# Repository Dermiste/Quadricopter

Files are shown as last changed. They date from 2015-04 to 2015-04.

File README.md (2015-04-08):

Quadricopter
============

## Cartes
Contient les schémas et empruntes de la carte mère (celle qui se trouve directement au dessus du Coldfire) ainsi que des 4 cartes mezzanines:
- le gyroscope                LG4200D
- l'accéléromètre             LIS331DLH
- l'accéléromètre + boussole  LMS303D
- le capteur de pression      LPS25h

## Controleur
Les sources du projet phonegap permettant de réaliser une télécommande sur smartphone/tablette

## Datasheet
Les datasheet de tous les capteurs utilisés + certains .pdf qui se sont avérés utiles

## Scilab Scripts
Tout le nécessaire pour pouvoir recevoir des données depuis la liaison série et ensuite les afficher dans un graph
À noter que l'installation d'une extension est nécessaire pour pouvoir faire fonctionner le script, disponible ici:
https://atoms.scilab.org/toolboxes/serialport

## Sources
Le code C utilisé dans le quadcopter.
Pour travailler sur un nouveau fichier basé sur l'existant, copier et renommer Sandbox.c qui contient le minimum vital (lecture capteur + filtrage) puis ajouter dans le makefile le nom du fichier dans la variable PGMs de la manière indiquée dans le commentaire juste au dessus. Noter que le makefile utilise un memory.x pour répartir certaines librairies entre la ROM et la RAM, d'ou les deux .s19 en sortie. Le "rom" est à uploader avec la sonde et ne change normalement pas (un seul upload donc, mais véto sur le "ne change pas") et le "ram" est à uploader avec dBug via un terminal.

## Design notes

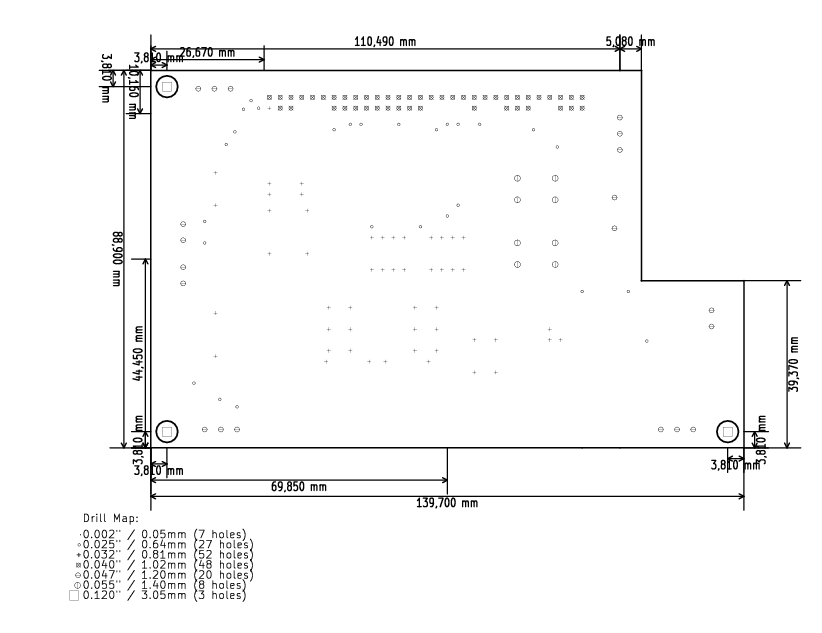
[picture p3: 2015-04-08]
Cartes/Mezanine/Image jpg pour rapport/plan de perçage.bmp

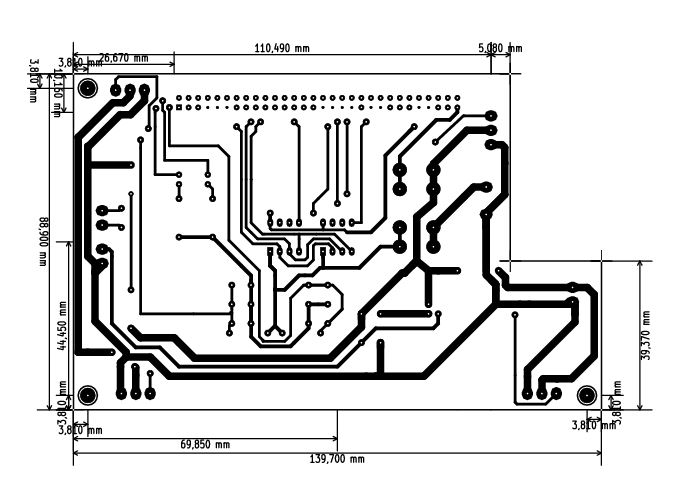
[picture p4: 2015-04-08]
Cartes/Mezanine/Image jpg pour rapport/typon dessous.bmp

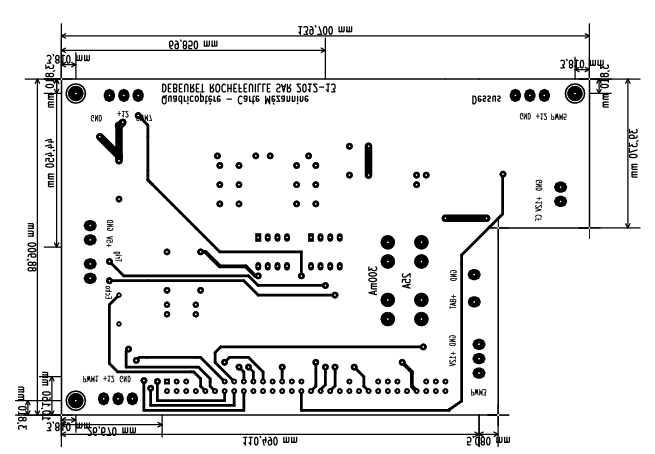
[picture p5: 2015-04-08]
Cartes/Mezanine/Image jpg pour rapport/typon dessus.bmp

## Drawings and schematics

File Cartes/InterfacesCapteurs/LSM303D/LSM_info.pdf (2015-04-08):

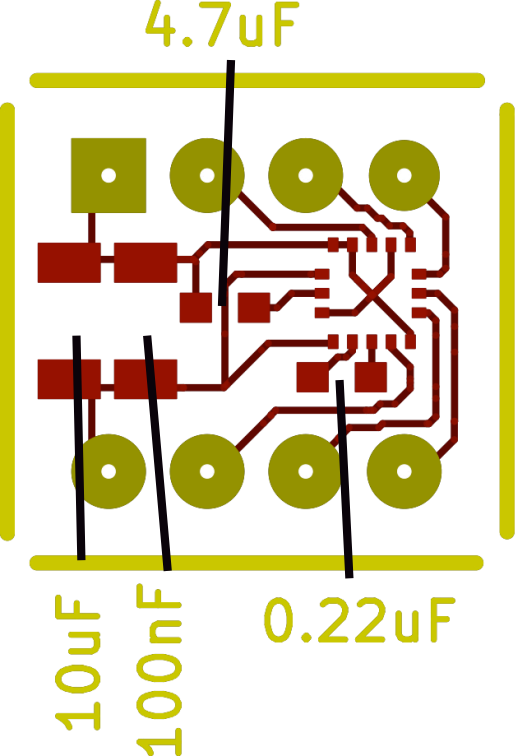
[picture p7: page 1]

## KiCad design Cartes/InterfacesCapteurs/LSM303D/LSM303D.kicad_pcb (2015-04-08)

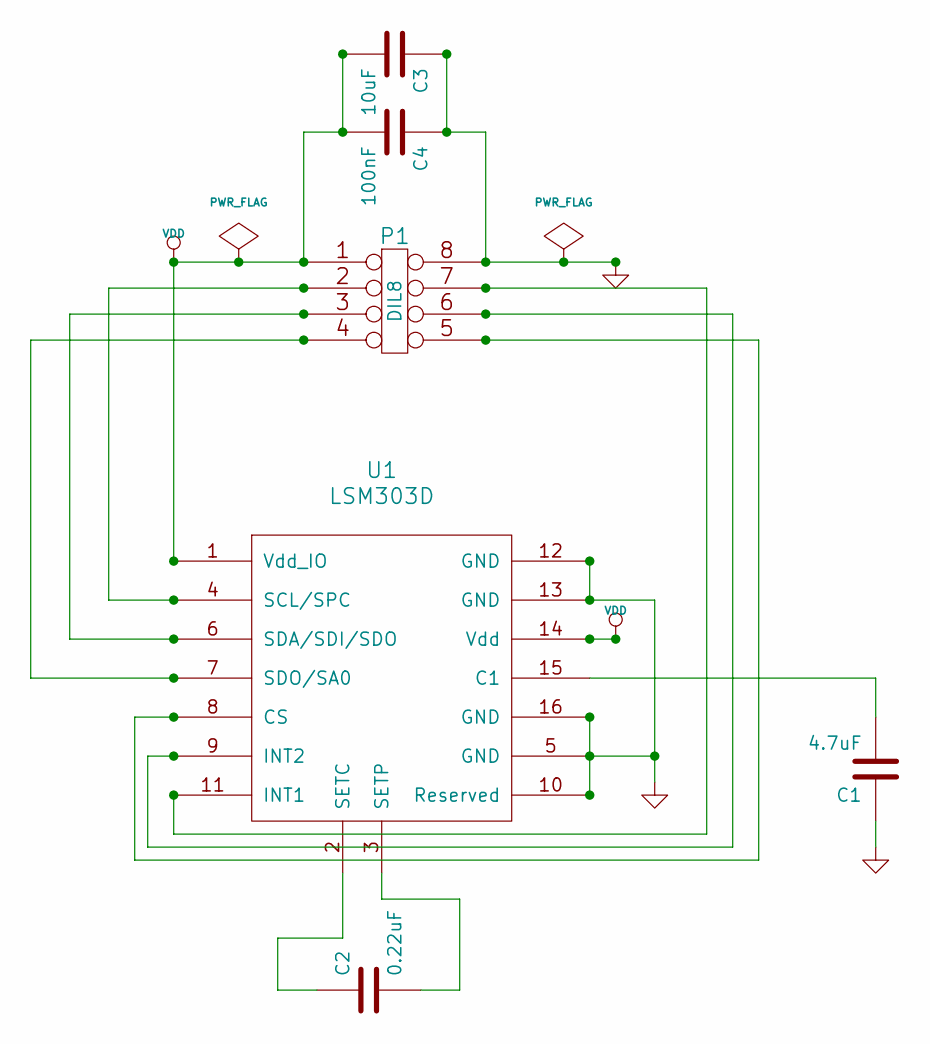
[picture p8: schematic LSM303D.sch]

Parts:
C1: 4.7uF
C2: 0.22uF
C3: 10uF
C4: 100nF
P1: DIL8
U1: LSM303D

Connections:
GND: C1.1, C3.1, C4.1, P1.8, U1.5 (GND), U1.10 (Reserved), U1.12 (GND), U1.13 (GND), U1.16 (GND)
unnamed: C1.2, U1.15 (C1)
unnamed: C2.1, U1.2 (SETC)
unnamed: C2.2, U1.3 (SETP)
unnamed: P1.2, U1.4 (SCL/SPC)
unnamed: P1.3, U1.6 (SDA/SDI/SDO)
unnamed: P1.4, U1.7 (SDO/SA0)
unnamed: P1.5, U1.8 (CS)
unnamed: P1.6, U1.9 (INT2)
unnamed: P1.7, U1.11 (INT1)
VDD: C3.2, C4.2, P1.1, U1.1 (Vdd_IO), U1.14 (Vdd)

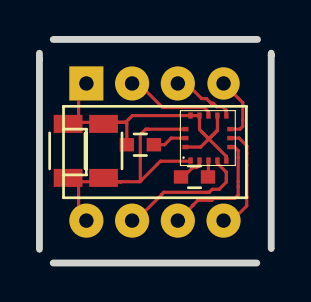
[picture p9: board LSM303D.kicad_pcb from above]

Board: 2 copper layers, 12.9 x 12.4 mm, 6 parts (0 on the bottom side), 11 nets.

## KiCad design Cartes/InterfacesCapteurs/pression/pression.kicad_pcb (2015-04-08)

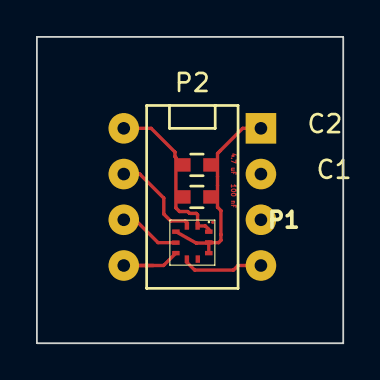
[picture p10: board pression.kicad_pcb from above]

Board: 2 copper layers, 17.0 x 17.0 mm, 4 parts (0 on the bottom side), 6 nets.

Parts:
C1: 4.7 uF; C_0603
C2: 100 uF; C_0603
P1: DIL10; HCLGA-10L
P2: DIL8; DIP-8__300

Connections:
/CLK: P1.2, P2.2
/CS: P1.6, P2.5
/SDI: P1.4, P2.3
/SDO: P1.5, P2.4
/Vcc: C1.1, C2.1, P1.1, P1.10, P2.1
GND: C1.2, C2.2, P1.3, P1.8, P1.9, P2.8

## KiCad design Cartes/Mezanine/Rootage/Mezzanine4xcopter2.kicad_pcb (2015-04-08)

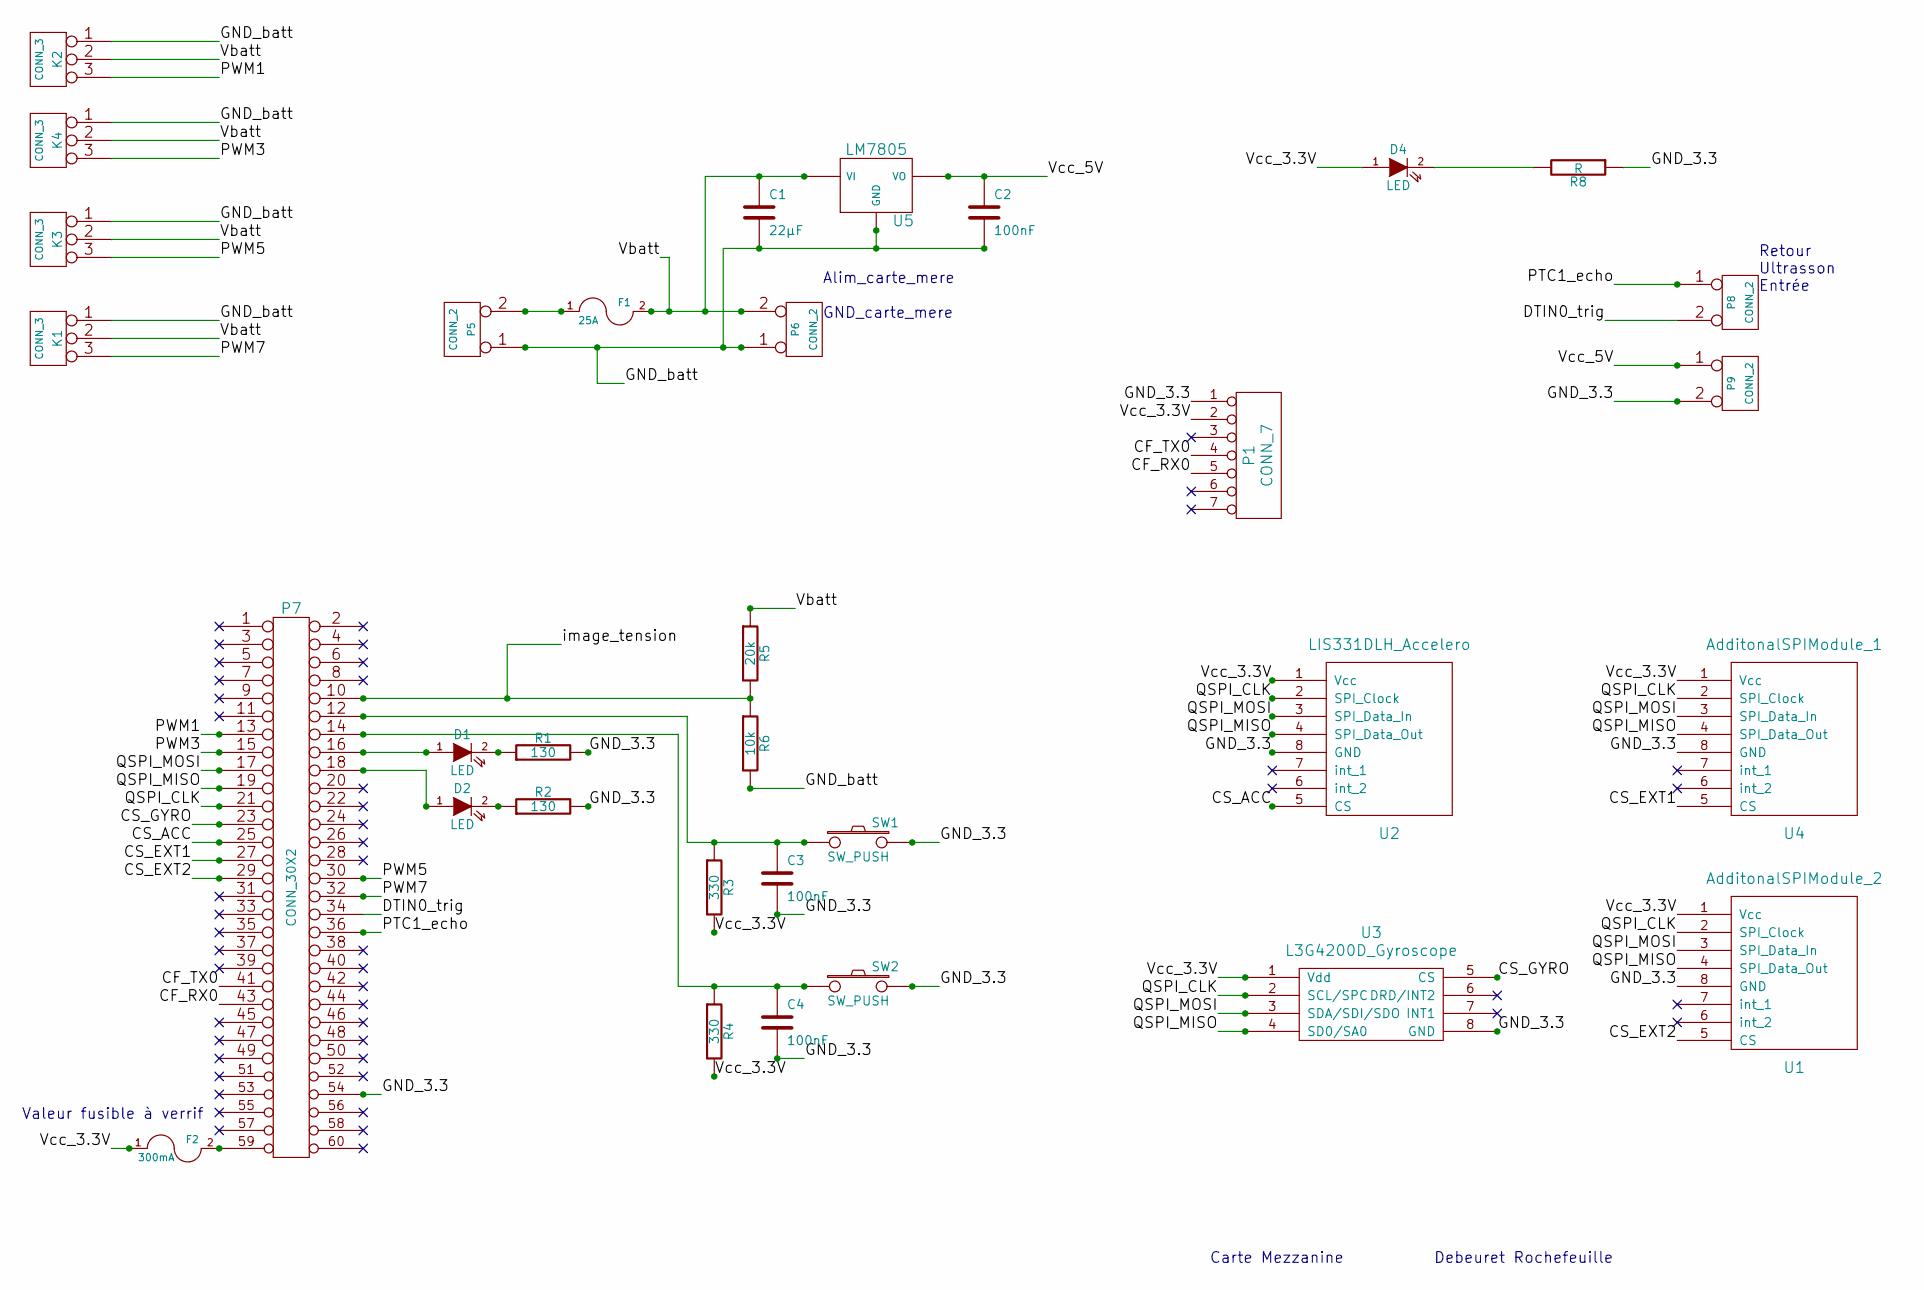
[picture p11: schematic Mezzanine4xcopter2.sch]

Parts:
C1: 22µF
C2, C3, C4: 100nF
D1, D2, D4: LED
F1: 25A
F2: 300mA
K1, K2, K3, K4: CONN_3
P1: CONN_7
P5, P6, P8, P9: CONN_2
P7: CONN_30X2
R1, R2: 130
R3, R4: 330
R5: 20k
R6: 10k
R8: R
SW1, SW2: SW_PUSH
U1: AdditonalSPIModule_2
U2: LIS331DLH_Accelero
U3: L3G4200D_Gyroscope
U4: AdditonalSPIModule_1
U5: LM7805

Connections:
/CF_RX0: P1.5, P7.43
/CF_TX0: P1.4, P7.41
/CS_ACC: P7.25, U2.5 (CS)
/CS_EXT1: P7.27, U4.5 (CS)
/CS_EXT2: P7.29, U1.5 (CS)
/CS_GYRO: P7.23, U3.5 (CS)
/DTIN0_trig: P7.34, P8.2 (PM)
/GND_3.3: C3.2, C4.2, P1.1, P7.54, P9.2 (PM), R1.2, R2.2, R8.1, SW1.2, SW2.2, U1.8 (GND), U2.8 (GND), U3.8 (GND), U4.8 (GND)
/GND_batt: C1.2, C2.2, K1.1, K2.1, K3.1, K4.1, P5.1, P6.1, R6.2, U5.GND
/PTC1_echo: P7.36, P8.1
/PWM1: K2.3, P7.13
/PWM3: K4.3, P7.15
/PWM5: K3.3, P7.30
/PWM7: K1.3, P7.32
/QSPI_CLK: P7.21, U1.2 (SPI_Clock), U2.2 (SPI_Clock), U3.2 (SCL/SPC), U4.2 (SPI_Clock)
/QSPI_MISO: P7.19, U1.4 (SPI_Data_Out), U2.4 (SPI_Data_Out), U3.4 (SD0/SA0), U4.4 (SPI_Data_Out)
/QSPI_MOSI: P7.17, U1.3 (SPI_Data_In), U2.3 (SPI_Data_In), U3.3 (SDA/SDI/SDO), U4.3 (SPI_Data_In)
/Vbatt: C1.1, F1.2, K1.2 (PM), K2.2 (PM), K3.2 (PM), K4.2 (PM), P6.2 (PM), R5.1, U5.VI
/Vcc_3.3V: D4.1 (A), F2.1, P1.2, R3.2, R4.2, U1.1 (Vcc), U2.1 (Vcc), U3.1 (Vdd), U4.1 (Vcc)
/Vcc_5V: C2.1, P9.1, U5.VO
/image_tension: P7.10, R5.2, R6.1
unnamed: C3.1, P7.12, R3.1, SW1.1
unnamed: C4.1, P7.14, R4.1, SW2.1
unnamed: D1.1 (A), P7.16
unnamed: D1.2 (K), R1.1
unnamed: D2.1 (A), P7.18
unnamed: D2.2 (K), R2.1
unnamed: D4.2 (K), R8.2
unnamed: F1.1, P5.2 (PM)
unnamed: F2.2, P7.59

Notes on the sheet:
Valeur fusible à verrif
Carte Mezzanine Debeuret Rochefeuille
Alim_carte_mere GND_carte_mere
Retour Ultrasson Entrée

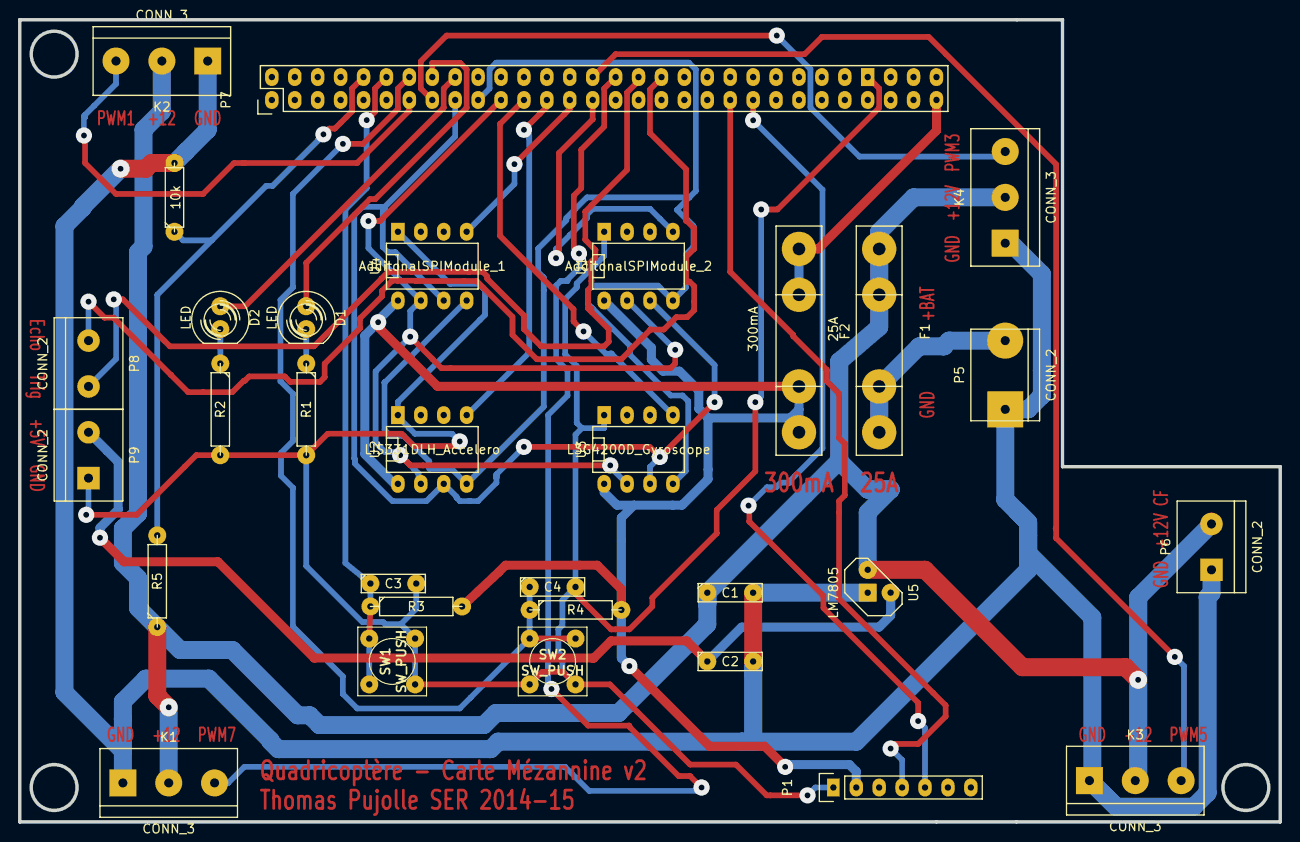
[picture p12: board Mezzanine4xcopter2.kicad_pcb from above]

Board: 2 copper layers, 139.7 x 88.9 mm, 31 parts (0 on the bottom side), 29 nets.

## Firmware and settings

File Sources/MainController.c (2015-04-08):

/* Projet : Quadricopter
fichier : 4xCopter.c
Objet : prog principal d'asservissement
autheurs : VG / J-E G-B
Version :	1.0 - 27-06-2013 Tests de base
			1.1 - 11-07-2013 Mise en route des moteurs !
*/

#include "stdio.h"
#include "main.h"
#include "config.h"
#include "libs/spiUtils/spiUtils.h"
#include "libs/mcf5213/mcf5213.h"
#include "libs/sensorUtils/sensorUtils.h"


#define NVECT_TMR0 (64 + 19)
#define NVECT_TMR1 (64 + 20)
#define NVECT_TMR2 (64 + 21)

#define ADR_VECT_INT0 (0x20000000 + NVECT_TMR0*4)
#define ADR_VECT_INT1 (0x20000000 + NVECT_TMR1*4)
#define ADR_VECT_INT2 (0x20000000 + NVECT_TMR2*4)

extern void isrINT0(void);
extern void isrSonar(void);
extern void isrTempo1ms(void);

void Init_5213(void);
void Init_PWM (void);
void receiveAndSendCommands();

int imageCap1 = 0, imageCap2 = 0, imagetemps;

char gyrData[3];
char accData[3];
char magData[3];
char buf[6];


int __errno=0;	//pour gestion messages d'erreur des fcts asin, acos de libm.a
int nirq = 0;
signed int moteur1,moteur2,moteur3,moteur4;

unsigned int initialThurst = 0;
int thrustOffset = 0;
int totalSample = 0;
unsigned int testMode = 0,shouldFinishTest = 0;

int altitudeSonar = 0, altitudeBaro = 0, pressure = 0;
int pitch = 0,roll = 0, yaw = 0;

int targetPitch = 0, targetRoll = 0, targetYawSpeed = 0;

int lastPitch = 0, lastRoll = 0, deltaPitch = 0, deltaRoll = 0;

int errorPitch = 0, errorRoll = 0, errorYawSpeed = 0;
int integratedErrorPitch = 0, integratedErrorRoll = 0, integratedErrorYawSpeed=0;

int control_roll=0,control_pitch=0,control_yaw=0;
int PTerm, ITerm, DTerm;
unsigned char m4offset = 3;
//int a=2,b=3,c=4;

char stepPID = 1;

char controlMode = 0,controlActivated = 0;
int a = 2, b = 3, c = 9;

signed int rollFromGyro=0, pitchFromGyro=0;
signed int pitchFromAcc=0, rollFromAcc=0;

unsigned char kP = 42, kI = 70, kD = 13;

int yawFromGyro = 0, intFromAcc = 0;

void actionINT0(void) {
	//MCF_DTIM0_DTER = MCF_DTIM_DTER_REF | MCF_DTIM_DTER_CAP;
}

void actionSonar(void) {
	if (imageCap1 == 0){
		imageCap1 = MCF_DTIM1_DTCR;
	} else {
		imageCap2 = MCF_DTIM1_DTCR;
		imagetemps=imageCap2-imageCap1;  //image impulsion = capture 2 -capture 1

		altitudeSonar=(imagetemps*100)/7000;

        imageCap1 = 0;	
       
	}

	MCF_DTIM1_DTER = MCF_DTIM_DTER_REF | MCF_DTIM_DTER_CAP;
}

void actionTempo1ms(void) {
	nirq++;
	switch(nirq){

		case 5000:		
			MCF_DTIM2_DTMR=0x500B;
			nirq = 0;
			shouldFinishTest = 1;
		break;
	}

	// Acquittement de l'interruption
	MCF_DTIM2_DTER = MCF_DTIM_DTER_REF | MCF_DTIM_DTER_CAP;
}


int main (void)
{	
	a = cos(b);
	c = sin(b);
	a = tan(b);
	c = atan(a);
	c = atan2(a,b);
	c = pow(a,b);


	controlMode = 0;
	controlActivated = 0;
	testMode = 0;


	printf("Starting ...:\n");
	char temp, choix,_r,_p;
	unsigned int i, throttle,st;
	throttle = 0,st = 0;
	printf("Reponse indicielle:\n");
	
	Init_5213();		
	Init_PWM();  
	Init_spi();
	int result = Init_sensors();
	while(!result && i){	//Init des composants
		printf("Erreur d'init Acc ou Gyro, retrying ...\n");
		result = Init_sensors();
	}



	getch();

	while(1)
	{
		while ((MCF_DTIM3_DTER & 2)==0);//attend prochain date ech
		MCF_DTIM3_DTER = 2;				//RAZ Flag


		MCF_GPIO_CLRTC=0x00;
		for(i=0;i<2000;i++); //Temporisation
		MCF_GPIO_SETTC=0x01;

		getIMUdata(accData, gyrData, magData);
		filterIMUdata(accData, gyrData, magData, &pitch, &roll, &yaw);

		errorPitch = targetPitch - pitch/10;
		errorRoll = targetRoll - roll/10;	

		//errorYawSpeed = targetYawSpeed - gyrData[2] * 3.906;

		integratedErrorPitch +=  errorPitch; 
		integratedErrorRoll  += errorRoll;
		//integratedErrorYawSpeed += errorYawSpeed;

		integratedErrorPitch = sat(integratedErrorPitch,-7000,7000);  
		integratedErrorRoll =  sat(integratedErrorRoll,-8000,8000);

		deltaRoll = roll - lastRoll;
		lastRoll = roll;	

		deltaPitch = pitch - lastPitch;
		lastPitch = pitch;

		PTerm = errorPitch / kP;
		//PTerm = sat(PTerm,-10,10); 

		ITerm = (integratedErrorPitch / freq) / kI;
		DTerm = deltaPitch / kD;

		control_pitch = PTerm;// + ITerm - DTerm;
		control_pitch += ITerm;
		control_pitch -= DTerm;

		control_roll = errorRoll / kP ;
		control_roll = (integratedErrorRoll / freq ) /  kI;
		control_roll -= deltaRoll / kD;

		//control_yaw = integratedErrorYawSpeed / freq / kI;	
		control_yaw = 0;		

		if (controlActivated){
			if (controlMode){
				//moteur1 =  throttle + st + control_roll;
				//moteur2 =  throttle + st - control_roll;

				moteur3 =  throttle + st + control_pitch;
				moteur4 =  throttle + st - control_pitch + m4offset;

				//MCF_PWM_PWMDTY7 = (unsigned char)sat(moteur1+110,100,210);	
				//MCF_PWM_PWMDTY3 = (unsigned char)sat(moteur2+110,100,210);

				MCF_PWM_PWMDTY5 = (unsigned char)sat(moteur3+110,100,190);
				MCF_PWM_PWMDTY1 = (unsigned char)sat(moteur4+110,100,190);	//on limite a 180 pour commencer...
				//
				throttle = 50;
				//printf("Pitch [%d, %d, %d, %d] \n",pitch/10,control_pitch,integratedErrorPitch,deltaPitch);
				//printf("Roll  [%d, %d, %d] \n",roll/10,errorRoll/10,inategratedErrorRoll/10);
				//printf("Yaw [%d] \n",errorYawSpeed);
				
			} else {
				//initialThurst = 120;
				MCF_PWM_PWMDTY7 = 0;
				MCF_PWM_PWMDTY3 = 0;

				MCF_PWM_PWMDTY5 = initialThurst;// - m4offset;
				MCF_PWM_PWMDTY1 = initialThurst + m4offset;
				throttle = 0;
			}
		} else {
			MCF_PWM_PWMDTY1 = 0;
			MCF_PWM_PWMDTY3 = 0;
			MCF_PWM_PWMDTY5 = 0;
			MCF_PWM_PWMDTY7 = 0;
		}
		 //PTC1=1;


		//MCF_DTIM0_DTER=0x03;
		//printf("Pulse ...\n");

		/*while((MCF_DTIM1_DTER & 0x01 )==0); // Capture 2
		MCF_DTIM1_DTER=0x03; //RAZ registre Drapeau
		imageCap2=MCF_DTIM1_DTCR; //capture 2

		printf("Capture 1 ...\n");

		while((MCF_DTIM1_DTER & 0x01 )==0); // Capture 2
		MCF_DTIM1_DTER=0x03; //RAZ registre Drapeau
		imageCap2=MCF_DTIM1_DTCR; //capture 2		

		printf("Capture 2 ...\n");*/


		 //PTC1=0;		
		//MCF_DTIM0_DTCN=0; //RAZ registre Compteur
		//MCF_DTIM0_DTER=0x03; //RAZ registre Drapeau







		if (testMode){
			if (shouldFinishTest){
				testMode = 0;
				shouldFinishTest = 0;				
				out_byte(1);	
			} else { 
				out_byte(0);
			}	


			/*out_byte(accData[2]);
			out_byte(gyrData[0]);
			out_byte(gyrData[1]);
			out_byte(gyrData[2]);*/
			//out_byte(pitchFromAcc/100);
			//out_byte(pitchFromGyro/100);
			//out_byte((char)(atan2(magData[0],magData[1]) * 180/3.1415));
			//out_byte(__atan2(magData[0],magData[1])/15);
			//out_byte(yaw/150);
			out_byte(magData[0]);
			out_byte(magData[1]);			
			//out_byte(control_pitch);
			//out_byte(control_roll);
		}
		/* Test clavier */
		if (kbhit()) {
			choix = getch();	//lire derniere touche appuyee
			switch (choix)
			{
			case 'z':
				SpiListSlaves();
			break;

			case '1':
				targetRoll = ((char)getch()) * 10;
				targetPitch = ((char)getch()) * 10;
			break;	

			case '=': // + sans le shift
				if (controlActivated)
			    initialThurst += 5;
				printf("Thrust %d\n",initialThurst);
			break;
			case '-':
				if (controlActivated)
				initialThurst -= 5;
				printf("Thrust %d\n",initialThurst);
			break;
			case 'b':
				if (controlActivated == 0){
					controlActivated = 1;
					initialThurst = 120;
				} else { 	
					if (controlMode == 1){
						controlMode = 0;
						initialThurst = 120;
					} else {
						controlMode = 1;
						integratedErrorPitch = 0;
						integratedErrorPitch = 0;
					}
				}	
			break;	
			case 'M':
				if (m4offset != 0){
					m4offset -- ;
					printf("m4offset %d\n",m4offset);
				}
			break;
			case 'm':
				m4offset += 1;
				printf("m4offset %d\n",m4offset);	
			break;	
			case 'p':
				kP += stepPID;
				printf("kP %d kI %d kD %d \n",kP,kI,kD);
			break;
			case 'i':
				kI += stepPID;
				printf("kP %d kI %d kD %d \n",kP,kI,kD);
			break;
			case 'd':
				kD += stepPID;
				printf("kP %d kI %d kD %d \n",kP,kI,kD);
			break;

			case 'P':
				kP -= stepPID;
				printf("kP %d kI %d kD %d \n",kP,kI,kD);
			break;
			case 'I':
				kI -= stepPID;
				printf("kP %d kI %d kD %d \n",kP,kI,kD);
			break;
			case 'D':
				kD -= stepPID;
				printf("kP %d kI %d kD %d \n",kP,kI,kD);
			break;			
			case 'e':
				printf("Pitch: %d Error Pitch: %d \n",pitch/10,errorPitch);
				printf("Roll: %d  Error Roll: %d \n",roll/10,errorRoll);
				printf("Compass: %d  %d  %d\n",magData[0],magData[1],magData[2]);	
			break;		
			case 'o':
				out_byte(accData[0]);
				out_byte(accData[1]);
				out_byte(accData[2]);
				out_byte(gyrData[0]);
				out_byte(gyrData[1]);
				out_byte(gyrData[2]);
				out_byte(pitchFromAcc/100);
				out_byte(pitchFromGyro/100);
				out_byte(pitch/100);
				out_byte(rollFromAcc/100);
				out_byte(rollFromGyro/100);
				out_byte(roll/100);
				out_byte(control_pitch);
				out_byte(control_roll);
			break;	

			case 'x':
				printf("Acc X:%d Y:%d Z:%d \n",accData[0],accData[1],accData[2]);
				printf("V 	X:%d Y:%d Z:%d \n",gyrData[0],gyrData[1],gyrData[2]);
				printf("Compass: X:%d  Y:%d  Z:%d\n\n",magData[0],magData[1],magData[2]);
				printf("Pitch : %d Roll : %d Yaw : %d\n",pitch/100, roll/100, yaw/100);	
				getAltitudeAndPressure(&altitudeBaro,&pressure);
				printf("Altitude: Sonar: %dcm Baro: %ddm Pression:%dpa \n\n",altitudeSonar, altitudeBaro, pressure);	

			break;
			case 'a':
				MCF_DTIM2_DTMR=0x501B;
				testMode = 1;


				rollFromGyro = 0;
				pitchFromGyro = 0;

				pitchFromAcc = 0;
				rollFromAcc = 0;

				integratedErrorPitch = 0;
			break;
		

			case (27):
			case (10):		// Arret d'urgence
				printf("Exit %d\n",choix);	
				printf("kP %d kI %d kD %d \n",kP,kI,kD);
				stopTest();
				return(0);
			break;
			}
		}
	}		
}



void stopTest(){
	initialThurst = 0;
    thrustOffset = 0;
	MCF_PWM_PWMDTY1 = 0;	//couper les PWM
	MCF_PWM_PWMDTY3 = 0;
	MCF_PWM_PWMDTY5 = 0;
	MCF_PWM_PWMDTY7 = 0;


	MCF_DTIM0_DTMR=0x500B;
	nirq = 0;
	testMode = 0;
}

void Init_PWM (void)
{
	MCF_GPIO_DDRTD = MCF_GPIO_DDRTD | 0x0F; 		//config en sortie TD0
	MCF_GPIO_PTDPAR = MCF_GPIO_PTDPAR | 0x0F;		// configure en PWM
	
	MCF_PWM_PWME = MCF_PWM_PWME | 0xAA; 			//active PWMOUT1
	MCF_PWM_PWMPOL = MCF_PWM_PWMPOL | 0xAA; 		//niveau bas au debut puis haut
	MCF_PWM_PWMCLK = MCF_PWM_PWMCLK | 0xAA; 		//selectionne la clock A / B 
	
	MCF_PWM_PWMPRCLK = MCF_PWM_PWMPRCLK | 0x11;		//divise l'horloge A / B par 4
	MCF_PWM_PWMCAE = MCF_PWM_PWMCAE & 0x55; 		//choisi l'alignement
	MCF_PWM_PWMCTL = MCF_PWM_PWMCTL & 0x0F; 		//PWM1 configuré sur 8bits
	MCF_PWM_PWMSDN = MCF_PWM_PWMSDN & 0xBF; 		//desactive les interruptions
	
	MCF_PWM_PWMSCLA = 0x63; 						//redivise la clock A par 52
	MCF_PWM_PWMSCLB = 0x63; 						//redivise la clock B par 52
	
	MCF_PWM_PWMPER1 = 0xFF; 						//periode de 255
	MCF_PWM_PWMPER3 = 0xFF; 						//periode de 255
	MCF_PWM_PWMPER5 = 0xFF; 						//periode de 255
	MCF_PWM_PWMPER7 = 0xFF; 						//periode de 255
}		

void Init_5213(void)
{  
	MCF_GPIO_PTCPAR = MCF_GPIO_PTCPAR & ~(MCF_GPIO_DDRTC_DDRTC0 | MCF_GPIO_DDRTC_DDRTC1); // OK // PAR, 0 for GPIO, 1 for primary function
	MCF_GPIO_PTCPAR = MCF_GPIO_PTCPAR | MCF_GPIO_DDRTC_DDRTC2;
	//printf("MCF_GPIO_PTCPAR 0x%x \n\n",MCF_GPIO_PTCPAR);

	MCF_GPIO_DDRTC = MCF_GPIO_DDRTC | MCF_GPIO_DDRTC_DDRTC0; // OK // DDR, set for output, clear for input
	MCF_GPIO_DDRTC = MCF_GPIO_DDRTC & ~MCF_GPIO_DDRTC_DDRTC1;
	//printf("MCF_GPIO_DDRTC 0x%x \n",MCF_GPIO_DDRTC);

	MCF_GPIO_PQSPAR = 0x0015;	//QS4 GPIO(CS Acc), QS3..1 en primary pour SPI	

	//Config Timer1 pour capture de l'écho du sonar
	MCF_DTIM1_DTMR=0x40C3; 
	MCF_DTIM1_DTRR=0xFFFFFFFF; 
	MCF_DTIM1_DTCN=0; //RAZ registre Compteur
	MCF_DTIM1_DTER=0x03; //RAZ registre Drapeaux

	MCF_INTC_ICR20 = MCF_INTC_ICR_IL(0x5); // Timer 1
	MCF_INTC_ICR21 = MCF_INTC_ICR_IL(0x5); // Timer 2
	MCF_INTC_IMRL = MCF_INTC_IMRL & ~(MCF_INTC_IMRL_MASK20 | MCF_INTC_IMRL_MASK21);
	
	io_32(ADR_VECT_INT1) = (long)isrSonar; // Chargement du vecteur d'interruption dans la table
	io_32(ADR_VECT_INT2) = (long)isrTempo1ms;
	__asm("move.w #0x2200,%sr\n");	 // Initialisation a 2 du masque de priorite d'interruption dans le registre d'etat	
	
	//Config Timer2 pour temporiser suites de commandes + impulsion sonar
	MCF_DTIM2_DTMR=0x500B; //RAZ auto, pas de prediv 16, pas d'IT 
	MCF_DTIM2_DTRR=1000; //Registre Reference pour 1MHz
	MCF_DTIM2_DTCN=0; //RAZ registre Compteur
	MCF_DTIM2_DTER=0x03; //RAZ registre Drapeaux	

	//Config Timer3 pour echantillonage 100Hz A PARTIR DE CLK+80MHZ
	//division par 80 par prediv puis ref=10000 => 100HZ
	MCF_DTIM3_DTMR=0x500B; //RAZ auto, pas de prediv 16, pas d'IT
	MCF_DTIM3_DTRR=9999; //Registre Reference pour 100Hz
	MCF_DTIM3_DTCN=0; //RAZ registre Compteur
	MCF_DTIM3_DTER=0x03; //RAZ registre Drapeaux	
}	

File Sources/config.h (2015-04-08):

#ifndef __CONFIG__
#define __CONFIG__

#define PI 3.141592654

#define dt 0.01
#define freq 100

#define timeConstant 0.5
#define compFilterCoef timeConstant / (timeConstant + dt)//0.9782;

#define ACCELEROMETER_SENSITIVITY 32.0 
#define GYROSCOPE_SENSITIVITY 17.5	

#define PRESSURE_REF 101325
#define PRESSURE_POW 0.190284
#define PRESSURE_MULT 44307.69

#endif /* __CONFIG__ */

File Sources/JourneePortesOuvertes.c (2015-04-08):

/* Projet : Quadricopter
fichier : 4xCopter.c
Objet : prog principal d'asservissement
autheurs : VG / J-E G-B
Version :	1.0 - 27-06-2013 Tests de base
			1.1 - 11-07-2013 Mise en route des moteurs !
*/

#include "stdio.h"
#include "main.h"
#include "config.h"
#include "libs/spiUtils/spiUtils.h"
#include "libs/mcf5213/mcf5213.h"
#include <math.h>


int rollFromGyro=0, pitchFromGyro=0;
int pitchFromAcc=0, rollFromAcc=0;


// moteur1 PWMDTY7
// moteur2 PWMDTY3
// moteur3 PWMDTY5
// moteur4 PWMDTY1

#define NVECT_TMR0 (64 + 19)
#define NVECT_TMR2 (64 + 21)
#define ADR_VECT_INT0 (0x20000000 + NVECT_TMR0*4)
#define ADR_VECT_INT2 (0x20000000 + NVECT_TMR2*4)

extern void isrINT0(void);
extern void isrINT2(void);

//Variables globales
char tabInertie[9];
	//contenu tabInertie : ThetaX, ThetaY, AccZ, dThetaX,dThetaY,dThetaZ,D²ThetaX,d²ThetaY,d²ThetaZ
char bufGyroOld[6];	//pour calcul derivee vitesse angulaire (acceleration angulaire)

char gyrData[3];
char accData[3];


int __errno=0;	//pour gestion messages d'erreur des fcts asin, acos de libm.a
int GvX,GvY,GvZ,GaX,GaY,IGpX,IGpY;	//gains asservissement
int SumAY=0,SumAX=0;	//moyennage Angles
char MoyAX,MoyAY;	//Angles moyennes
int nirq = 0;
signed int moteur1,moteur2,moteur3,moteur4;
unsigned char PWMot1,PWMot2,PWMot3,PWMot4;

unsigned long timeClock,startTime = 0;
unsigned int initialThurst = 0;
int thrustOffset = 0;
int totalSample = 0;
unsigned int testMode = 0,shouldFinishTest = 0;


void Init_5213(void);
void Init_PWM (void);
void ComplementaryFilter(char aData[3], char gData[3], int *pitch, int *roll);
int __atan2(float y, float x);


void GetInertie(void);

int pitch = 0,roll = 0;

int lastPitch, lastRoll, deltaPitch, deltaRoll;
int targetPitch = 0, targetRoll = 0, targetYawSpeed = 0;
int errorPitch = 0, errorRoll = 0, errorYawSpeed = 0;
int integratedErrorPitch = 0, integratedErrorRoll = 0, integratedErrorYawSpeed=0;
int control_roll=0, control_pitch=0, control_yaw=0;

int PTerm, ITerm, DTerm;

char controlMode = 0,controlActivated = 0;

char appState = 'a';

int thrustOn = 0;
int a = 2, b = 3, c = 9;

unsigned char m4offset = 5;

#define dt 0.01
#define freq 100

#define timeConstant 0.5
#define compFilterCoef timeConstant / (timeConstant + dt)//0.9782;

unsigned char kP = 28, kI = 46, kD = 11; // idea: 19 70 5

int shouldTrace = 0;

void actionINT0(void) {
	//unsigned int ii;
	/*nirq++;
	switch(nirq){
		case 1:
			thrustOffset = 0;
			initialThurst = 0;
		break;

		case 120:
			initialThurst = 120;
		break;	

		case 220:
			initialThurst = 120;
		break;	


		case 320:
			initialThurst = 120;
		break;			

		case 440:		
			thrustOffset = 0;
			initialThurst = 0;
			MCF_DTIM0_DTMR=0x500B;
			nirq = 0;
			shouldFinishTest = 1;
		break;
	}	//printf("Occurence num. %d de TIMER1 \n", nirq);

	// Acquittement de l'interruption
	MCF_DTIM0_DTER = MCF_DTIM_DTER_REF | MCF_DTIM_DTER_CAP;*/
}

void actionINT2(void) {
	//unsigned int ii;
	timeClock += 1;
	// Acquittement de l'interruption
	MCF_DTIM2_DTER = MCF_DTIM_DTER_REF | MCF_DTIM_DTER_CAP;
}

int main (void)
{	
	controlMode = 0;
	controlActivated = 0;
	testMode = 0;

	printf("Starting ...:\n");
	char temp, choix,_r,_p;
	unsigned int i, throttle,st;
	throttle = 0,st = 0;
	
	
/*Init des IOs*/	
	Init_5213();		//bus SPI
	Init_PWM();
	int result = Init_sensors();
	while(!result){	//Init des composants
		printf("Erreur d'init Acc ou Gyro, retrying ...\n");
		result = Init_sensors();
	}
	printf("Script journées portes ouvertes. Controles:\n");
	printf("Ech: quitter\n");
	printf("o: 12 octets de données de vol\n");
	printf("x: ces mêmes octets mis en formes\n");
	printf("z: mets à zero les angles déterminés selon le gyro\n");
	printf("m1: allume les moteurs à 120\n");
	printf("m0: etteint les moteurs\n");
	getch();
	

	while(1)
	{
		while ((MCF_DTIM3_DTER & 2)==0);//attend prochain date ech
		MCF_DTIM3_DTER = 2;				//RAZ Flag

		GetInertie();	//remplacer par les nouvelles fonctions, voir Sandbox ou MainController
		ComplementaryFilter(accData,gyrData,&pitch,&roll);

	

		errorPitch = targetPitch - pitch/10;
		errorRoll = targetRoll - pitch/10;

		control_pitch = errorPitch / kP;
		control_roll = errorRoll / kP;

		if (appState == 'a'){
			throttle = 0;
			MCF_PWM_PWMDTY7 = throttle;
			MCF_PWM_PWMDTY3 = throttle;

			MCF_PWM_PWMDTY5 = throttle;
			MCF_PWM_PWMDTY1 = throttle;
		} else if (appState == 'b'){
			throttle = 120;
			MCF_PWM_PWMDTY7 = 0;
			MCF_PWM_PWMDTY3 = 0;

			MCF_PWM_PWMDTY5 = throttle;
			MCF_PWM_PWMDTY1 = throttle;

		} else if (appState == 'c'){
			return;
			kP = 15;
			throttle = 20;

			//moteur1 =  throttle + st + control_roll;
			//moteur2 =  throttle + st - control_roll;

			moteur3 =  throttle + control_pitch;
			moteur4 =  throttle - control_pitch + m4offset;

			//MCF_PWM_PWMDTY7 = (unsigned char)sat(moteur1+110,100,135);	
			//MCF_PWM_PWMDTY3 = (unsigned char)sat(moteur2+110,100,135);

			MCF_PWM_PWMDTY5 = (unsigned char)sat(moteur3+110,100,135);
			MCF_PWM_PWMDTY1 = (unsigned char)sat(moteur4+110,100,135);	
		} else if (appState == 'D'){
			return;
			kP = 28;
			throttle = 60;

			errorPitch = targetPitch - pitch/10;

			integratedErrorPitch +=  errorPitch; 
			integratedErrorPitch = sat(integratedErrorPitch,-8000,8000);  		

			deltaPitch = pitch - lastPitch;
			lastPitch = pitch;

			PTerm = errorPitch / kP;
			ITerm = (integratedErrorPitch / freq) / kI;
			DTerm = deltaPitch / kD;

			control_pitch = PTerm + ITerm - DTerm;

			moteur3 =  throttle + st + control_pitch;
			moteur4 =  throttle + st - control_pitch + m4offset;

			MCF_PWM_PWMDTY7 = 0;	
			MCF_PWM_PWMDTY3 = 0;

			MCF_PWM_PWMDTY5 = (unsigned char)sat(moteur3+110,100,190);
			MCF_PWM_PWMDTY1 = (unsigned char)sat(moteur4+110,100,190);	//on limite a 180 pour commencer...
			//
		}

		/*if (thrustOn == 1){
			throttle = 20;

			moteur1 =  throttle + st + control_roll;
			moteur2 =  throttle + st - control_roll;

			moteur3 =  throttle + control_pitch;
			moteur4 =  throttle - control_pitch + m4offset;

			//MCF_PWM_PWMDTY7 = (unsigned char)sat(moteur1+110,100,135);	
			//MCF_PWM_PWMDTY3 = (unsigned char)sat(moteur2+110,100,135);

			MCF_PWM_PWMDTY5 = (unsigned char)sat(moteur3+110,100,135);
			MCF_PWM_PWMDTY1 = (unsigned char)sat(moteur4+110,100,135);	
			printf("Control pitch [%d] \n",control_pitch);		
 
		} else {
			throttle = 0;
			MCF_PWM_PWMDTY7 = throttle;
			MCF_PWM_PWMDTY3 = throttle;

			MCF_PWM_PWMDTY5 = throttle;
			MCF_PWM_PWMDTY1 = throttle;
		}*/

		/* Test clavier */
		if (kbhit())
			{
				choix = getch();	//lire derniere touche appuyee
				switch (choix)
				{	
				case '1':
					targetRoll = (char)getch();
					targetPitch = (char)getch();
				break;
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

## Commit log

2015-01-14 Extracted functions to imuUtils
2015-04-08 Last modification
    [$savepcb.brd, 2_25_20:9:39_imuData.csv, 2_25_20_1_10_imuData.csv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]
2015-04-08 Added phonegap controller
    [BluefruitLE.fzz]
